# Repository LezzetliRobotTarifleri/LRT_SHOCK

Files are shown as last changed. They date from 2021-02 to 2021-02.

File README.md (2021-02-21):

# LRT_SHOCK
Real users will feel real pain at games.

LRT_SHOCK projesi farklı oyunlardan oyuncunun can verisini çekerek bu veriye bağlı olarak gerçek hayatta elektrik şoku alarak acı çekmesini ve farklı bir deneyim elde etmesini amaçlayan açık kaynak kodlu deneysel bir projedir ve youtube/lezzetlirobottarifleri kanalında yayınlanmaktadır.

Proje hakkındaki güncellemeler https://www.youtube.com/lezzetlirobottarifleri kanalından takip edilebilir.

Proje her ne kadar eğlence amaçlı tasarlanmış olsada tehlikeli bir projedir ve 15 yaş altı, 50 yaş üstü, herhangi bir sağlık sorunu olan kişiler, hamileler, kalp pili kullananlar ve elektronik konusunda amatör olan kişiler tarafından kullanılmamalıdır. 

Kurulum aşamaları için bu video şimdilik iş görür:
https://www.youtube.com/watch?v=wtrCjeJp03g&feature=youtu.be

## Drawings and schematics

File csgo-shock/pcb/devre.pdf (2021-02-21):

# GND SHOCK

# 220 ¹N⁴¹⁴⁸

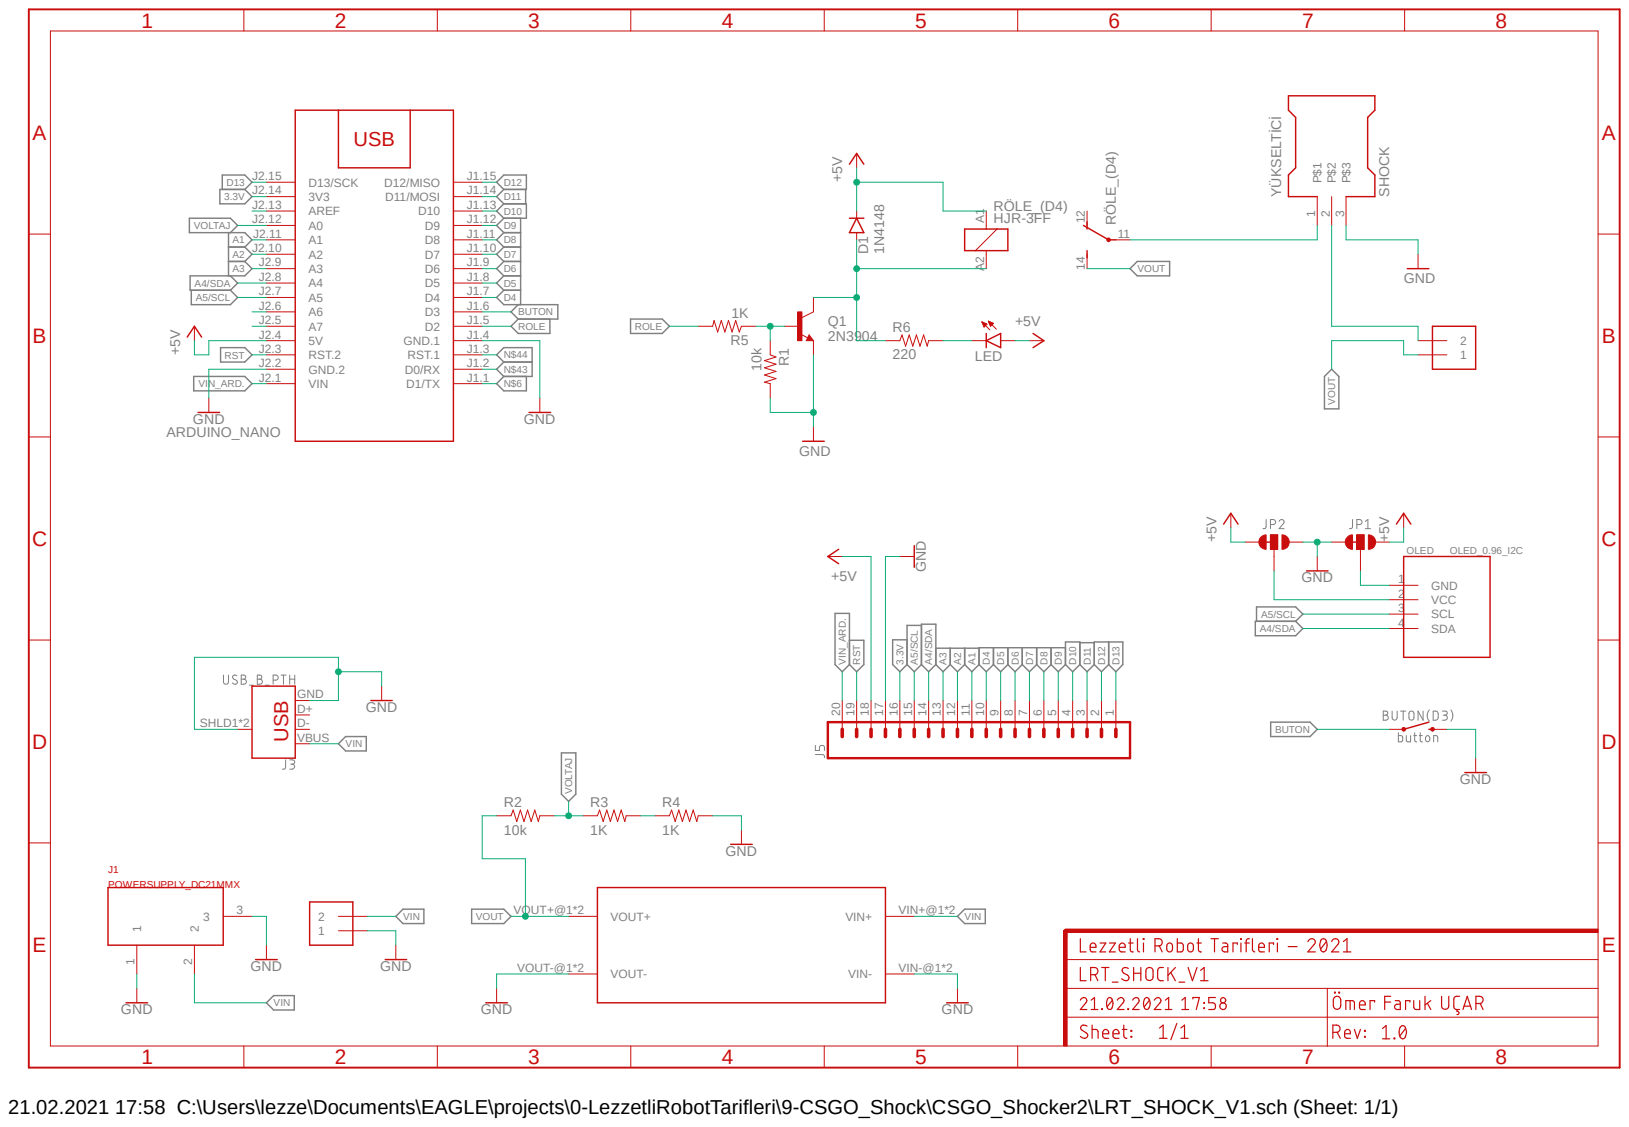
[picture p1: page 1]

21.02.2021 17:58 C:\Users\lezze\Documents\EAGLE\projects\0-LezzetliRobotTarifleri\9-CSGO_Shock\CSGO_Shocker2\LRT_SHOCK_V1.sch (Sheet: 1/1)

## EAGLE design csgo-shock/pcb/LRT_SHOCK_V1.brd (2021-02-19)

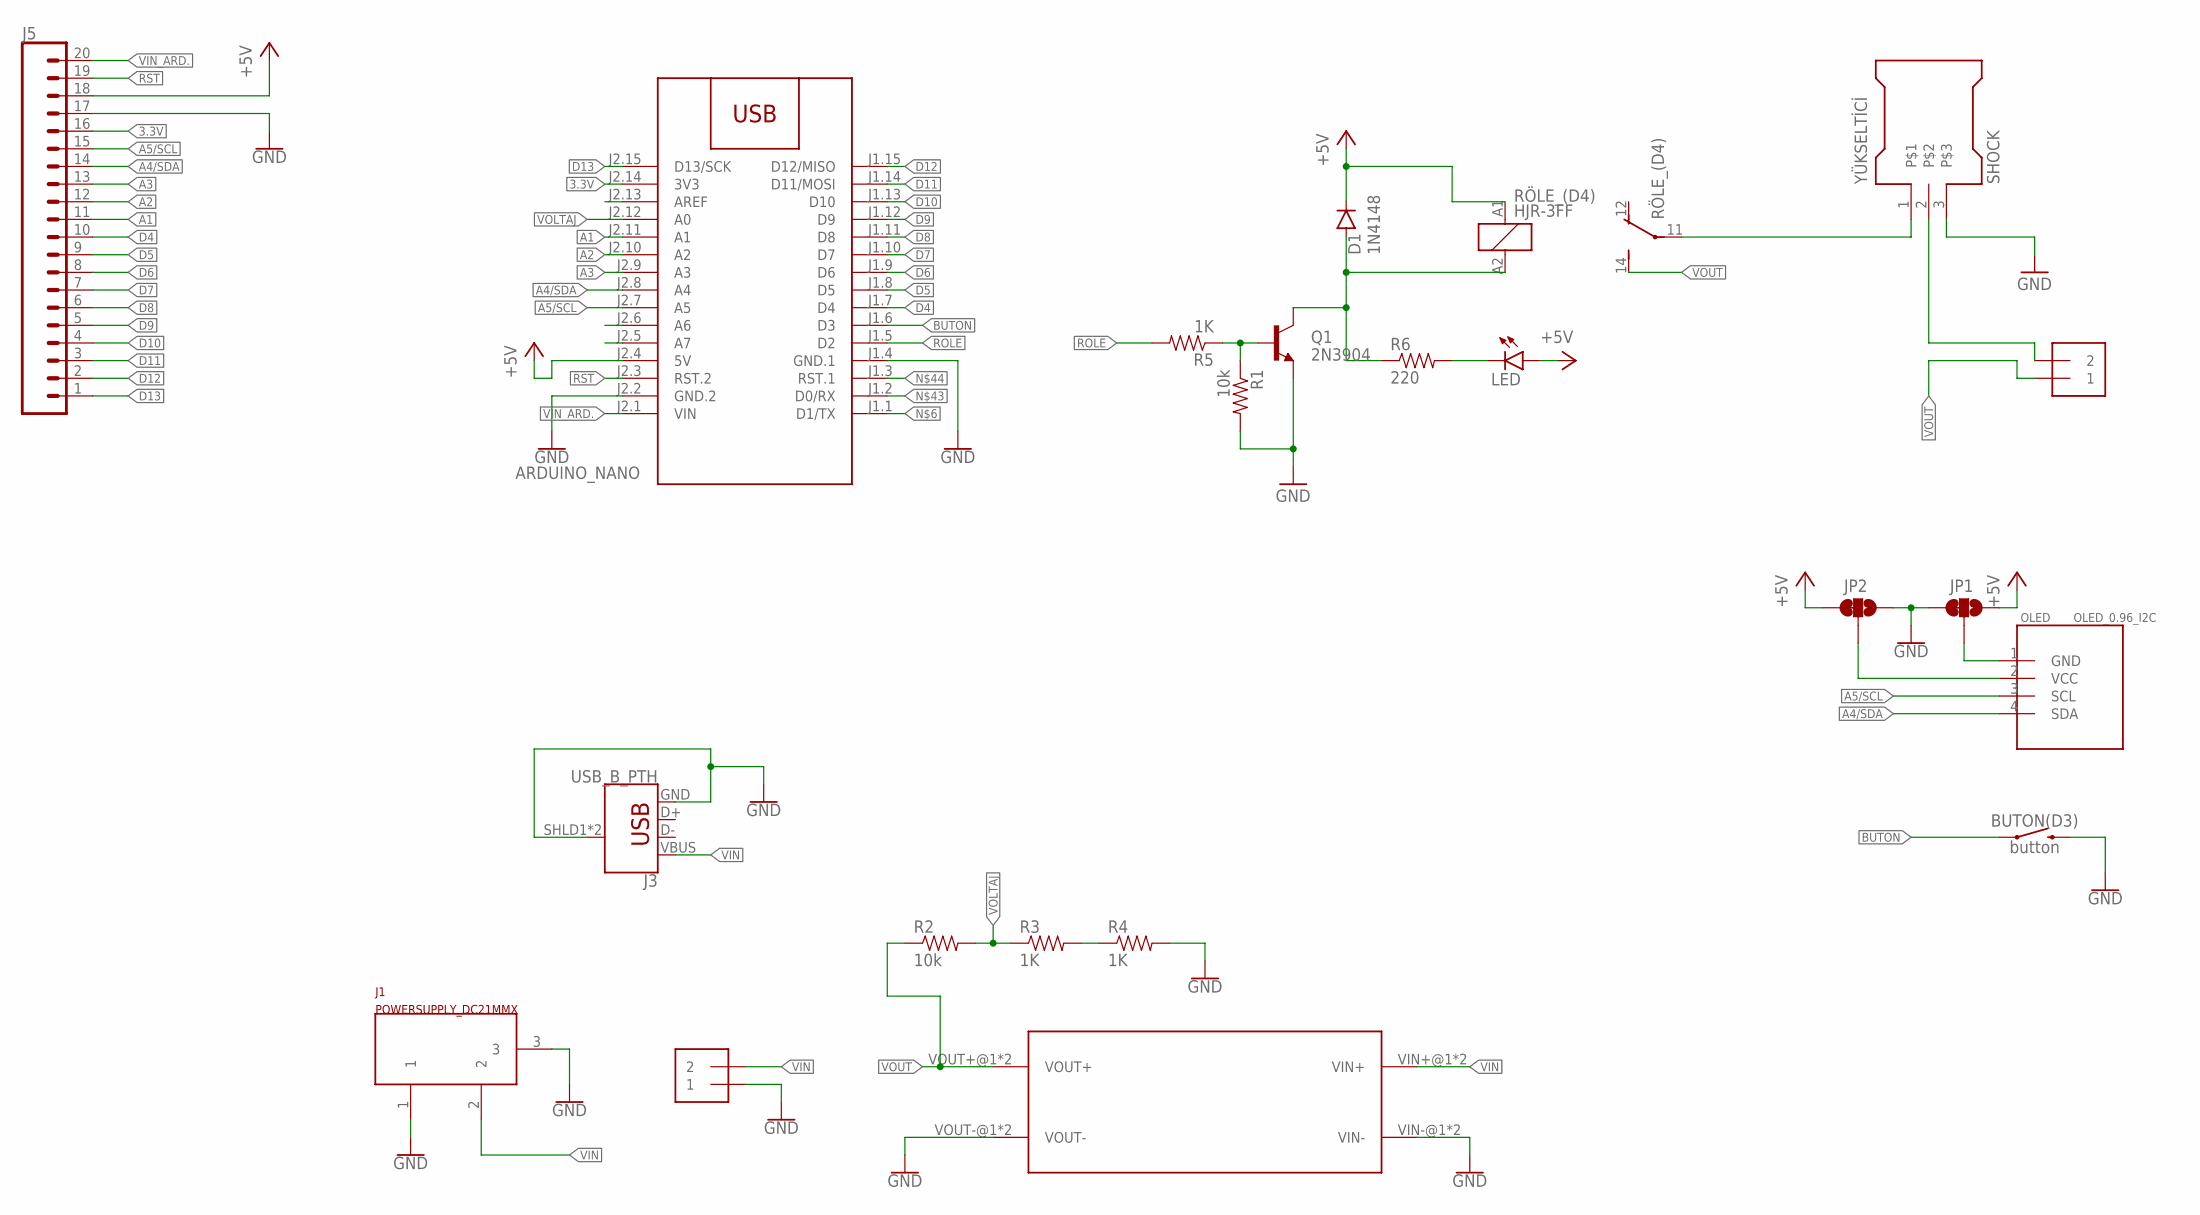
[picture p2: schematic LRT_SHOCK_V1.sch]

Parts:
ARDUINO_NANO: ARDUINO-NANO
BUTON(D3): button; TACTILE_SWITCH_PTH_12MM
D1: 1N4148; DIODE-1N4148-KIT
J1: POWERSUPPLY_DC21MMX; POWERSUPPLY_DC-21MM
J2: 1X2-3.5MM
J3: USB_B_PTH; USB-B-PTH
J5: CONN_20; 1X20
JP1, JP2: JUMPER-SMT_3_1-NC_TRACE_SILK; SMT-JUMPER_3_1-NC_TRACE_SILK
LED: LED5MM-KIT
MT3608: MT3608MT3608_2; MT3608_2
OLED: OLED_0.96_I2C
Q1: 2N3904; TO-92-EZ
R1, R2: 10k; AXIAL-0.3EZ
R3, R4, R5: 1K; AXIAL-0.3EZ
R6: 220; AXIAL-0.3EZ
RÖLE_(D4): HJR-3FF; ZN5
SHOCK!!: 1X2-3.5MM
YÜKSELTİCİ: SHOCK

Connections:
3.3V: ARDUINO_NANO.J2.14 (3V3), J5.16
+5V: ARDUINO_NANO.J2.4 (5V), D1.C, J5.18, JP1.1, JP2.3, LED.A, RÖLE_(D4).A1 (1)
A1: ARDUINO_NANO.J2.11 (A1), J5.11
A2: ARDUINO_NANO.J2.10 (A2), J5.12
A3: ARDUINO_NANO.J2.9 (A3), J5.13
A4/SDA: ARDUINO_NANO.J2.8 (A4), J5.14, OLED.4 (SDA)
A5/SCL: ARDUINO_NANO.J2.7 (A5), J5.15, OLED.3 (SCL)
BUTON: ARDUINO_NANO.J1.6 (D3), BUTON(D3).1
D4: ARDUINO_NANO.J1.7 (D4), J5.10
D5: ARDUINO_NANO.J1.8 (D5), J5.9
D6: ARDUINO_NANO.J1.9 (D6), J5.8
D7: ARDUINO_NANO.J1.10 (D7), J5.7
D8: ARDUINO_NANO.J1.11 (D8), J5.6
D9: ARDUINO_NANO.J1.12 (D9), J5.5
D10: ARDUINO_NANO.J1.13 (D10), J5.4
D11: ARDUINO_NANO.J1.14 (D11/MOSI), J5.3
D12: ARDUINO_NANO.J1.15 (D12/MISO), J5.2
D13: ARDUINO_NANO.J2.15 (D13/SCK), J5.1
GND: ARDUINO_NANO.J1.4 (GND.1), ARDUINO_NANO.J2.2 (GND.2), BUTON(D3).3 (2), J1.1, J1.3, J2.1, J3.GND, J3.SHLD1 (SHIELD), J3.SHLD2 (SHIELD), J5.17, JP1.3, JP2.1, MT3608.VIN-@1 (VIN-), MT3608.VIN-@2 (VIN-), Q1.1 (E), R1.P$2 (2), R4.P$2 (2), YÜKSELTİCİ.3
unnamed: MT3608.VOUT-@1 (VOUT-), MT3608.VOUT-@2 (VOUT-)
unnamed: SHOCK!!.2, YÜKSELTİCİ.2
unnamed: R3.P$2 (2), R4.P$1 (1)
unnamed: JP1.2, OLED.1 (GND)
unnamed: D1.A, Q1.3 (C), R6.P$1 (1), RÖLE_(D4).A2 (2)
unnamed: Q1.2 (B), R1.P$1 (1), R5.P$1 (1)
unnamed: LED.K (C), R6.P$2 (2)
unnamed: RÖLE_(D4).11, YÜKSELTİCİ.1
unnamed: JP2.2, OLED.2 (VCC)
ROLE: ARDUINO_NANO.J1.5 (D2), R5.P$2 (2)
RST: ARDUINO_NANO.J2.3 (RST.2), J5.19
VIN: J1.2, J2.2, J3.VBUS, MT3608.VIN+@1 (VIN+), MT3608.VIN+@2 (VIN+)
VIN_ARD.: ARDUINO_NANO.J2.1 (VIN), J5.20
VOLTAJ: ARDUINO_NANO.J2.12 (A0), R2.P$2 (2), R3.P$1 (1)
VOUT: MT3608.VOUT+@1 (VOUT+), MT3608.VOUT+@2 (VOUT+), R2.P$1 (1), RÖLE_(D4).14 (S), SHOCK!!.1

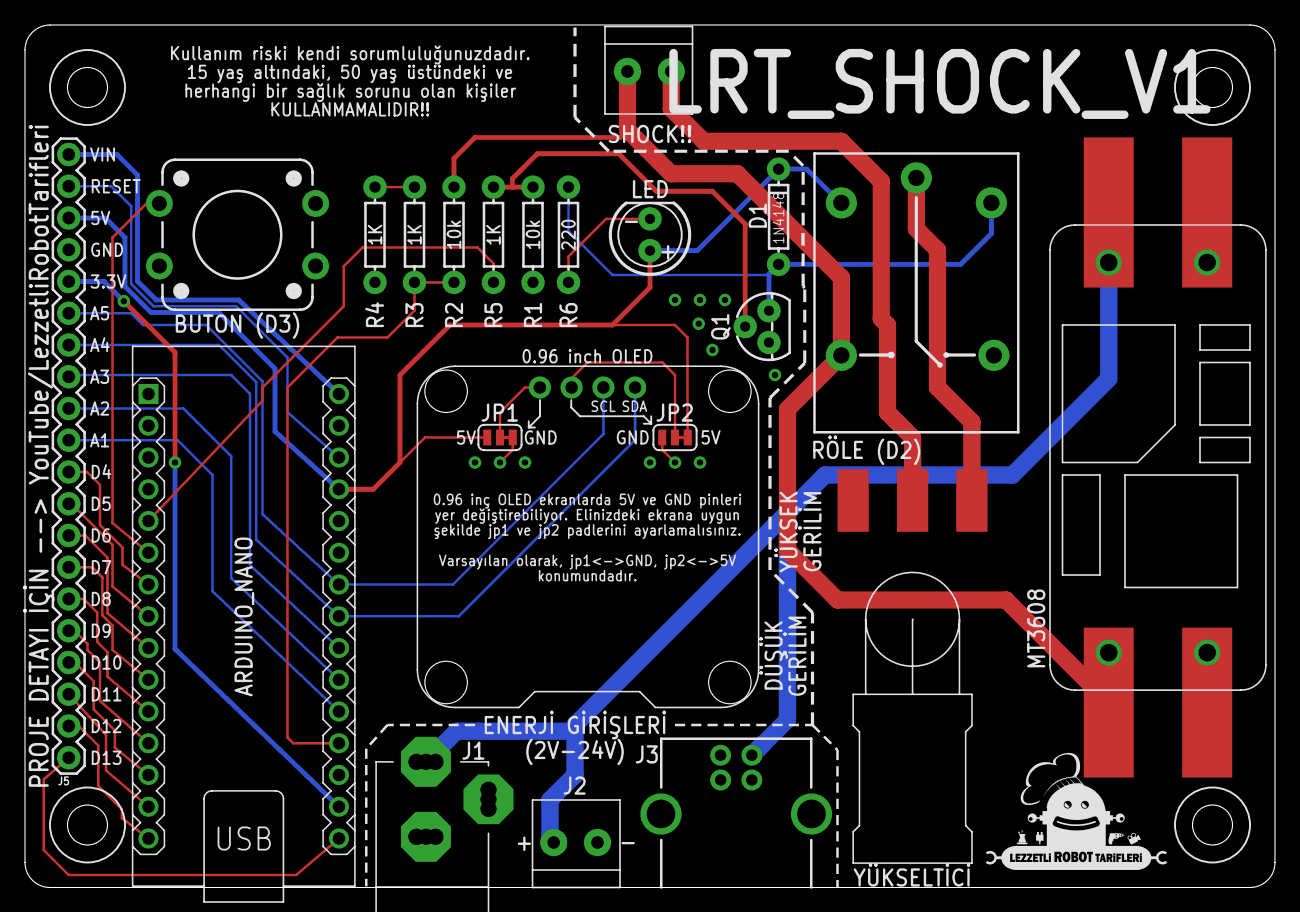
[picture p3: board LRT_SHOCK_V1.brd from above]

Board: 2 copper layers, 100.0 x 69.0 mm, 24 parts (1 on the bottom side), 34 nets.

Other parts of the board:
U$3: LRT-LOGO-0,0125-B
U$4: LRT-LOGO-0,10416-B-N_I

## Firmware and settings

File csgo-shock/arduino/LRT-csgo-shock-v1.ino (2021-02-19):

/**************************************************************************
  Bu örnek kod Lezzetli Robot Tarifleri projesi olan LRT-Shock için
  Ömer Faruk Uçar tarafından yazılmıştır.

  Gönül rahatlığı ile kullanabilir, geliştirebilir ve isterseniz tekrar
  topluluk ile paylaşabilirsiniz :)

  Bu arduino kodunda Adafruit tarafından geliştirilen ve açık kaynak paylaşılan
  "Adafruit_GFX" ve "Adafruit_SSD1306" kütüphaneleri kullanılmıştır.
  Kendilerinden satın alma yaparak onlara destek vermeyi düşünebilirsiniz.
  https://www.adafruit.com/

                                ****DİKKAT!****
  Kullanim riski kendi sorumluluğunuzdadır.15 yas alti, 50 yaş üstü, herhangi sağlık
  sorunu olan kişiler, elektronik konusunda amatör olanlar, asla KULLANMAMALIDIR!!

  Versiyon 1.0.0
 **************************************************************************/

//******Arduino tarafında kullanılan pinler ve çarpam süresi tanımlaması*******
#define BUTTON 3
#define RELAY 2
#define SENSOR A0
#define STRIKE_TIME 50 //(ms)

//**********************Kütüphane tanımlamaları********************************
#include <SPI.h>
#include <Wire.h>
#include <Adafruit_GFX.h>
#include <Adafruit_SSD1306.h>

//**********************Oled Ekren Tanımlamaları*******************************
#define SCREEN_WIDTH 128 // OLED ekran piksel cinsinden genişlik
#define SCREEN_HEIGHT 64 // OLED ekran piksel cinsinden yükseklik
#define OLED_RESET 4
#define LOGO_HEIGHT   64  //proje logosu yükseklik
#define LOGO_WIDTH    128 //proje logosu yükseklik
static const unsigned char PROGMEM logo_bmp[] =
{
  0x00, 0x00, 0x00, 0x00, 0x00, 0x00, 0x00, 0x00, 0x00, 0x00, 0x00, 0x00, 0x0F, 0xF0, 0x00, 0x00,
  0x00, 0x00, 0x00, 0x00, 0x00, 0x00, 0x00, 0x00, 0x00, 0x00, 0x00, 0x00, 0x7F, 0xFC, 0x00, 0x00,
  0x00, 0x00, 0x00, 0x00, 0x00, 0x00, 0x00, 0x00, 0x00, 0x00, 0x00, 0x01, 0xF8, 0x7E, 0x00, 0x00,
  0x00, 0x00, 0x00, 0x00, 0x00, 0x00, 0x00, 0x00, 0x00, 0x00, 0x00, 0x03, 0xC0, 0x1F, 0x00, 0x00,
  0x00, 0x00, 0x60, 0x07, 0xFC, 0xFF, 0xC0, 0x00, 0x00, 0x00, 0x00, 0x07, 0x80, 0x0F, 0x00, 0x00,
  0x00, 0x00, 0x60, 0x07, 0xFC, 0xFF, 0xC0, 0x00, 0x00, 0x00, 0x00, 0x0F, 0x00, 0x07, 0x80, 0x00,
  0x00, 0x00, 0x60, 0x06, 0x06, 0x0C, 0x00, 0x00, 0x00, 0x00, 0x00, 0x0E, 0x00, 0x07, 0x80, 0x00,
  0x00, 0x00, 0x60, 0x06, 0x06, 0x0C, 0x00, 0x00, 0x00, 0x00, 0x1F, 0xFE, 0x00, 0x07, 0x80, 0x00,
  0x00, 0x00, 0x60, 0x06, 0x06, 0x0C, 0x00, 0x00, 0x00, 0x00, 0xFF, 0xFE, 0x00, 0x03, 0x80, 0x00,
  0x00, 0x00, 0x60, 0x06, 0x06, 0x0C, 0x00, 0x00, 0x00, 0x01, 0xFF, 0xFF, 0x00, 0x03, 0x80, 0x00,
  0x00, 0x00, 0x60, 0x06, 0x06, 0x0C, 0x00, 0x00, 0x00, 0x07, 0xF0, 0x00, 0x00, 0x03, 0x80, 0x00,
  0x00, 0x00, 0x60, 0x07, 0xFC, 0x0C, 0x00, 0x00, 0x00, 0x0F, 0xC0, 0x00, 0x00, 0x03, 0x80, 0x00,
  0x00, 0x00, 0x60, 0x07, 0xFC, 0x0C, 0x00, 0x00, 0x00, 0x1F, 0x00, 0x00, 0x00, 0x03, 0x80, 0x00,
  0x00, 0x00, 0x60, 0x06, 0x70, 0x0C, 0x00, 0x00, 0x00, 0x1E, 0x00, 0x00, 0x00, 0x07, 0x80, 0x00,
  0x00, 0x00, 0x60, 0x06, 0x38, 0x0C, 0x00, 0x00, 0x00, 0x3C, 0x00, 0x00, 0x00, 0x07, 0x80, 0x00,
  0x00, 0x00, 0x60, 0x06, 0x3C, 0x0C, 0x00, 0x00, 0x00, 0x78, 0x00, 0x00, 0x00, 0x07, 0x80, 0x00,
  0x00, 0x00, 0x60, 0x06, 0x1C, 0x0C, 0x00, 0x00, 0x00, 0x70, 0x00, 0x00, 0x00, 0x0F, 0x00, 0x00,
  0x00, 0x00, 0x7F, 0xC6, 0x0E, 0x0C, 0x00, 0x00, 0x00, 0x70, 0x00, 0x00, 0x00, 0x1E, 0x00, 0x00,
  0x00, 0x00, 0x7F, 0xC6, 0x04, 0x0C, 0x00, 0x00, 0x00, 0xE0, 0x00, 0x00, 0x01, 0xFE, 0x00, 0x00,
  0x00, 0x00, 0x00, 0x00, 0x00, 0x00, 0x00, 0x00, 0x00, 0xE0, 0x00, 0x00, 0x1F, 0xF3, 0x00, 0x00,
  0x00, 0x00, 0x00, 0x00, 0x00, 0x00, 0x00, 0x00, 0x00, 0xE0, 0x00, 0x00, 0x7E, 0x63, 0x80, 0x00,
  0x00, 0x00, 0x00, 0x00, 0x00, 0x00, 0x00, 0x00, 0x00, 0xE0, 0x00, 0x01, 0xE3, 0x31, 0xC0, 0x00,
  0x00, 0x00, 0x00, 0x00, 0x00, 0x00, 0x00, 0x00, 0x00, 0xE0, 0x00, 0x07, 0xB1, 0xB8, 0xE0, 0x00,
  0x00, 0x00, 0x00, 0x00, 0x00, 0x00, 0x00, 0x00, 0x00, 0xF0, 0x00, 0x0E, 0x19, 0xFF, 0xE0, 0x00,
  0x00, 0x00, 0x00, 0x00, 0x00, 0x00, 0x00, 0x00, 0x00, 0xF8, 0x00, 0x1F, 0x1F, 0xFF, 0xF0, 0x00,
  0x0F, 0xE1, 0x81, 0x83, 0xF8, 0x1F, 0xC1, 0x81, 0x00, 0xF8, 0x00, 0x39, 0x8F, 0xFF, 0xFE, 0x00,
  0x1F, 0xF1, 0x81, 0x87, 0xFC, 0x3F, 0xE1, 0x83, 0x80, 0xF0, 0x00, 0x70, 0xFF, 0xFF, 0xFF, 0x80,
  0x38, 0x11, 0x81, 0x8E, 0x0E, 0x70, 0x71, 0x87, 0x01, 0xC0, 0x00, 0xE0, 0x7F, 0xFF, 0xFF, 0xE0,
  0x38, 0x01, 0x81, 0x8C, 0x06, 0x60, 0x31, 0x8E, 0x03, 0x80, 0x00, 0xC1, 0xFF, 0xFF, 0xFF, 0xF0,
  0x38, 0x01, 0x81, 0x8C, 0x06, 0x60, 0x31, 0x9C, 0x07, 0x80, 0x01, 0x83, 0xFF, 0xFF, 0xFF, 0xF8,
  0x1E, 0x01, 0x81, 0x8C, 0x06, 0x60, 0x01, 0xB8, 0x07, 0x00, 0x03, 0x07, 0xFF, 0xFF, 0xFF, 0xFC,
  0x1F, 0x01, 0xFF, 0x8C, 0x06, 0x60, 0x01, 0xF0, 0x0E, 0x00, 0x02, 0x0F, 0xFF, 0xFF, 0xFF, 0xFE,
  0x07, 0xC1, 0xFF, 0x8C, 0x06, 0x60, 0x01, 0xF8, 0x0E, 0x00, 0x06, 0x1F, 0xFF, 0xFF, 0xFF, 0xFF,
  0x01, 0xE1, 0x81, 0x8C, 0x06, 0x60, 0x01, 0xD8, 0x0E, 0x00, 0x04, 0x3F, 0xFF, 0xFF, 0xFF, 0xFF,
  0x00, 0x71, 0x81, 0x8C, 0x06, 0x60, 0x01, 0xDC, 0x0E, 0x00, 0x08, 0x3F, 0xFF, 0xFF, 0xFF, 0xFF,
  0x00, 0x31, 0x81, 0x8C, 0x06, 0x60, 0x01, 0x8E, 0x0E, 0x00, 0x00, 0x7F, 0xFF, 0xFF, 0xFF, 0xFF,
  0x00, 0x31, 0x81, 0x8C, 0x06, 0x60, 0x21, 0x86, 0x0E, 0x00, 0x60, 0x7F, 0xFF, 0xFF, 0xFF, 0xFF,
  0x10, 0x71, 0x81, 0x8E, 0x0E, 0x70, 0x71, 0x87, 0x0F, 0x01, 0xE0, 0xFF, 0xFF, 0xFF, 0xFF, 0xFF,
  0x3F, 0xE1, 0x81, 0x87, 0xFC, 0x3F, 0xE1, 0x83, 0x87, 0xFF, 0xC0, 0xFF, 0xFE, 0x7F, 0xF3, 0xFF,
  0x0F, 0xC1, 0x81, 0x83, 0xF8, 0x1F, 0xE1, 0x81, 0x03, 0xFF, 0x00, 0xFF, 0xFF, 0x3F, 0xF9, 0xFF,
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
};


//*********I2C üzerinden bağlanan ekran için tanımlama (SDA, SCL pins)*****************
#define OLED_RESET     4 // Reset pin # (or -1 if sharing Arduino reset pin)
Adafruit_SSD1306 display(SCREEN_WIDTH, SCREEN_HEIGHT, &Wire, OLED_RESET);


//************************Projede kullanılan değişkenler***************************
float Vout = 0.00;
float Vin = 0.00;
float R1 = 10000.00; // resistance of R1 (10K)
float R2 = 2000.00; // resistance of R2 (2K)
int val = 0;
const byte numChars = 32;
char receivedChars[numChars];
boolean newData = false;
boolean newSeparation = false;
int newValue = 100;
int oldValue = 100;

void setup()
{
  Serial.begin(9600); // seri haberleşme başlat

  //************************ Pin Mod Atamaları ***************************
  pinMode(RELAY, OUTPUT);
  pinMode(BUTTON, INPUT_PULLUP);
  pinMode(SENSOR, INPUT);

  //************************ Ekranı I2C Adresi ile Başlat ***************************
  if (!display.begin(SSD1306_SWITCHCAPVCC, 0x3C))
  {
    for (;;); // Don't proceed, loop forever
  }

  // Ekran buffer temizle
  display.clearDisplay();
  display.display();
  delay(2000);


  // display.display() buffer değişiklik yapıldıktan sonra ekrana değişikliklerin
  // yansıtılması için çağırılması gerekir.
  while (1)
  {
    logo_drawbitmap();
    delay(1000);
    display.clearDisplay();
    display.setCursor(0, 0);
    display.setTextSize(2);
    display.setTextColor(SSD1306_WHITE);
    display.println(" BASLAMAK ");
    display.println("   iCiN   ");
    display.println("  BUTONA  ");
    display.println(" BASINIZ! ");
    display.display();
    delay(2000);
    if (digitalRead(BUTTON) == 0)
    {
      while (digitalRead(BUTTON) == 0);
      break;
    }
  }
  while (1)
  {
    display.clearDisplay();
    display.setCursor(0, 0);
    display.setTextSize(2);             // Draw 2X-scale text
    display.setTextColor(SSD1306_WHITE);
    display.println("");
    display.println("  DiKKAT  ");
    display.println("");
    display.display();
    delay(1000);

    display.clearDisplay();
    display.setTextSize(1);             // Normal 1:1 pixel scale
    display.setTextColor(SSD1306_WHITE);        // Draw white text
    display.setCursor(0, 0);            // Start at top-left corner
    display.println("Kullanim riski kendi");
    display.println("sorumlulugunuzdadir.");
    display.println("15 yas alti, 50 yas");
    display.println("ustu, herhangi saglik");
    display.println("sorunu olan kisiler,");
    display.println("elektronik konusunda ");
    display.println("amator olanlar, asla ");
    display.println("  KULLANMAMALIDIR!!");

    display.display();
    delay(5000);
    if (digitalRead(BUTTON) == 0)
    {
      while (digitalRead(BUTTON) == 0);
      break;
    }
  }
}

void loop()
{
  //******************* Buton ile hızlı şok kontrol *****************
  if (digitalRead(BUTTON) == 0)
  {
    digitalWrite(RELAY, 1);
    delay(STRIKE_TIME);
    digitalWrite(RELAY, 0);
    while (digitalRead(BUTTON) == 0);
  }
  else
    digitalWrite(RELAY, 0);

  //******************* Ekrana çarpılacak olan voltaj seviyesini yazdıran kısım *****************
  val = analogRead(A0);//reads the analog input
  Vout = (val * 5.00) / 1024.00; // formula for calculating voltage out i.e. V+, here 5.00
  Vin = Vout / (R2 / (R1 + R2)); // formula for calculating voltage in i.e. GND
  if (Vin < 0.09) //şartlandırma
  {
    Vin = 0.00; 
  }
  Vin = Vin * 30;
  display.setTextSize(2);
  display.setTextColor(WHITE);
  display.setCursor(20, 25);
  display.println(Vin);
  display.display();
  delay(100);
  display.clearDisplay();

 //****** Oyundan gelen yeni verilerin işlendiği fonksiyonlar **********
  recvDataWithEndMarker();
  showNewData();


}
void recvDataWithEndMarker()
{
  static byte ndx = 0;
  char endMarker = '*';
  char rc;

  while (Serial.available() > 0 && newData == false)
  {
    rc = Serial.read();
    if (rc != endMarker) {
      receivedChars[ndx] = rc;
      ndx++;
      if (ndx >= numChars) {
        ndx = numChars - 1;
      }
    }
    else {
      receivedChars[ndx] = '\0';
      ndx = 0;
      newData = true;
    }
  }
}
void showNewData()
{
  if (newData == true) {

    newValue = atoi(receivedChars);
    newData = false;
    if (newValue == 100)
      oldValue = 100;
    if (((oldValue - newValue ) > 10))
    {
      digitalWrite(RELAY, 1);
      delay(STRIKE_TIME);
      digitalWrite(RELAY, 0);
      oldValue = newValue;
    }
  }
}
void logo_drawbitmap(void) {
  display.clearDisplay();

  display.drawBitmap(
    (display.width()  - LOGO_WIDTH ) / 2,
    (display.height() - LOGO_HEIGHT) / 2,
    logo_bmp, LOGO_WIDTH, LOGO_HEIGHT, 1);
  display.display();
  delay(1000);
}

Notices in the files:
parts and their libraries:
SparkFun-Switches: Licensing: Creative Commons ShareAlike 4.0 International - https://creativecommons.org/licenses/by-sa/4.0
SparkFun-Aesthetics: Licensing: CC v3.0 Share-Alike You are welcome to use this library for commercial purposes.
